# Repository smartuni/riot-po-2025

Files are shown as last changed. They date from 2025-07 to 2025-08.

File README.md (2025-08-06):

# RIOT im Internet of Things, Sommersemester 2025

Welcome to the primary repository of the RIOT im Internet of Things project for the Summer 2025 semester at HAW Hamburg. The project was concerned with designing, implementing and presenting technologies to improve the city of Hamburg's methods of managing its harbor's floodgates.

## The Current Situation

Currently, the methods for ensuring floodgates are closed in the event of a flood are inefficient. Field workers receive orders, send updates and otherwise communicate with the central office via walkie-talkies. The central office relies on pen-and-paper record-keeping to log events, such as gates being opened or closed.

## Our Proposed Solution

The solution proposed and developed by our team is as follows: 
<ul>
  <li>Floodgates will be fitted with sensors, called "GateMates," which autonomously report the state of the gate (open or closed) to a server located in the central office.</li>
  <li>Field workers will be issued devices, called "SenseMates," which receive orders from the central office. SenseMates will also record the state of nearby gates by communicating with the GateMates, enabling workers to confirm or refute the state reported by the GateMate.</li>
  <li>The workers at the office will be given a web app with a user interface, allowing them to track the status of gates in real time, as well as providing a digital record of the status of gates and allowing them to issue orders without the need for walkie-talkie communication.</li>
</ul>

Our proposed solution replaces the inefficient methods currently used by the city of Hamburg with fast and reliable digital methods, saving crucial time in the event of a flood.

## How to start the project

### SenseGate

- Connect to Power
- Wait until blue LED is on
- Red LED indicates if door is open (LED off) or closed (LED on)
- Blue LED indicates, if a state update is in progress (LED off). 
- There is a time runoff, which is triggered/restarted on any sensor input. When blue LED is on, the update is processed and sent via LoraWAN.    

#### Deployment

Before flashing make sure [signature keys](nodes/firmware/custom-modules/key-distro/README.md) are generated! 

#### Testing 

```make all flash RIOT_CONFIG_USE_TEST=1```

#### Production

```make all flash RIOT_CONFIG_DEVICE_ID=<GATE_ID>```

### SenseMate

#### Startup
- Use power switch
- Wait until screen is ready

#### Deployment

Before flashing make sure [signature keys](nodes/firmware/custom-modules/key-distro/README.md) are generated! 

#### Testing 

```make all flash RIOT_CONFIG_USE_TEST=1```

#### Production

```make all flash RIOT_CONFIG_DEVICE_ID=<GATE_ID>```

### How to start frontend and backend

#### Requirements to Start the Frontend
- nodejs installed
- npm installed

#### Frontend StartUp
[frontend StartUp](server/frontend/README.md)

#### Backend StartUp
[backend StartUp](server/backend/README.md)

## Nodes

### Overview <div id='overview'/>

SenseMate <div id='overview-sensemate'/>

- node carried around by workers
- receive from and propagate data to other nodes via BLE-module
- receive from and send data to server via LoRa-module

SenseGate <div id='overview-sensegate'/>

- node attached to flood gates
- receive from and propagate data to other nodes via BLE-module
- receive from and send data to server via LoRa-module

Server <div id='overview-server'/>

- receive from and send data to nodes via LoRa-Module
- display real-time accumulated data

## Used Hardware <div id='used-hardware'/>

- Board: Nordic nRF52840
- Power Switch
- Battery
- Thumbwheel
- Navigation
- Display
- Soundbuzzer
- Vibrationmotor

**SenseMate** is a battery-powered IoT device for monitoring and controlling floodgates. It communicates over BLE and LoRaWAN and provides tactile, visual, and acoustic feedback.

## Key Features <div id='key-features'/>

- **MCU**: [Adafruit Feather nRF52840 Sense](https://www.digikey.de/de/products/detail/adafruit-industries-llc/4516/11684829) (nRF52840 with BLE)
- **LoRa Module**: [Adafruit RFM95W](https://www.digikey.de/de/products/detail/adafruit-industries-llc/3231/6193593)
- **LoRa Antenna**: [Molex 2111400100](https://www.digikey.de/de/products/detail/molex/2111400100/9953925)
- **OLED Display**: [AZDelivery 0.96" SSD1306 I2C](https://www.amazon.de/AZDelivery-Display-Arduino-Raspberry-gratis/dp/B074NJMPYJ?th=1)
- **Thumbwheel Switch**: [SparkFun COM-08184](https://www.digikey.de/de/products/detail/sparkfun-electronics/08184/8543391)
- **Buzzer**: [TDK PS1240P02BT](https://www.digikey.de/de/products/detail/tdk-corporation/PS1240P02BT/935924) (connected to A2)
- **Vibration Motor**: [Seeed 316040004](https://www.digikey.de/de/products/detail/seeed-technology-co-ltd/316040004/5487673) (via NPN + GPIO D3)
- **Power Switch**: [C&K OS102011MA1QN1](https://www.digikey.de/de/products/detail/c-k/OS102011MA1QN1/1981430)
- **Battery**: [Amazon LiPo 1S 450mAh](https://www.amazon.de/dp/B0C5LD55HN) 

## Pinout Summary <div id='pin-summary'/>

| Peripheral         | Connection Type   | MCU Pin       |
|--------------------|-------------------|----------------|
| LoRa SPI           | SPI               | SCK / MOSI / MISO |
| LoRa CS            | GPIO              | D10            |
| LoRa RST           | GPIO              | D9             |
| LoRa IRQ (DIO0)    | GPIO              | D6             |
| LoRa DIO1 / DIO2   | GPIO              | D5 / D4        |
| OLED Display       | I²C               | SDA / SCL      |
| Thumbwheel         | Digital Inputs    | A0 / A1 / A3   |
| Buzzer             | PWM/GPIO          | A2             |
| Vibration Motor    | GPIO (via NPN)    | D3             |
| Battery Voltage    | Analog Input      | A6             |

---

This document is intended for firmware developers. All components are prewired—just refer to the pinout and RIOT board support to begin implementing logic.

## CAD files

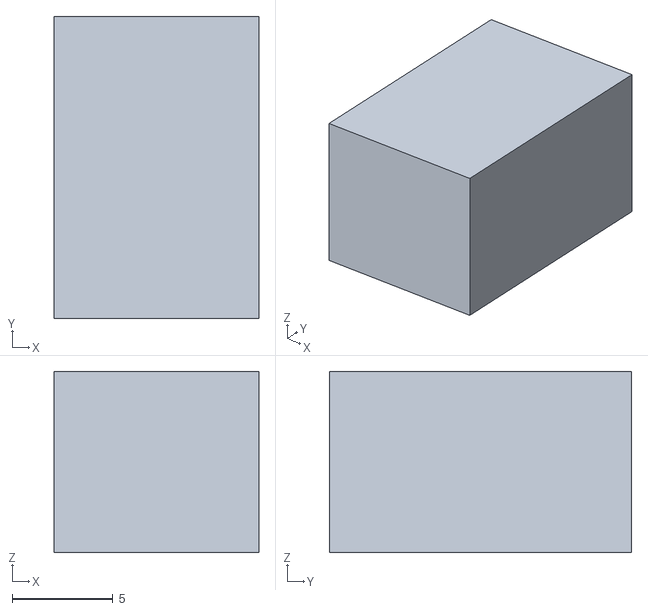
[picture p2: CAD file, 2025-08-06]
nodes/hardware/SenseMate/SenseMate3D/Case_v2.2_PCBBracket.stl
10.2 x 15.0 x 9.00

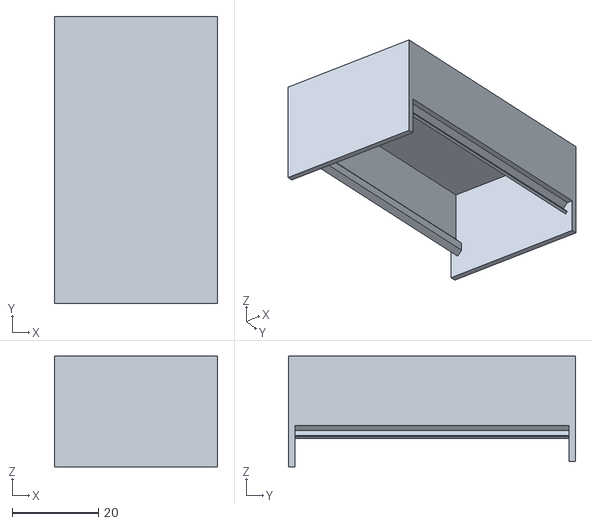
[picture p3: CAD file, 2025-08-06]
nodes/hardware/SenseMate/SenseMate3D/Case_v2.2_Back.stl
37.7 x 66.5 x 25.6

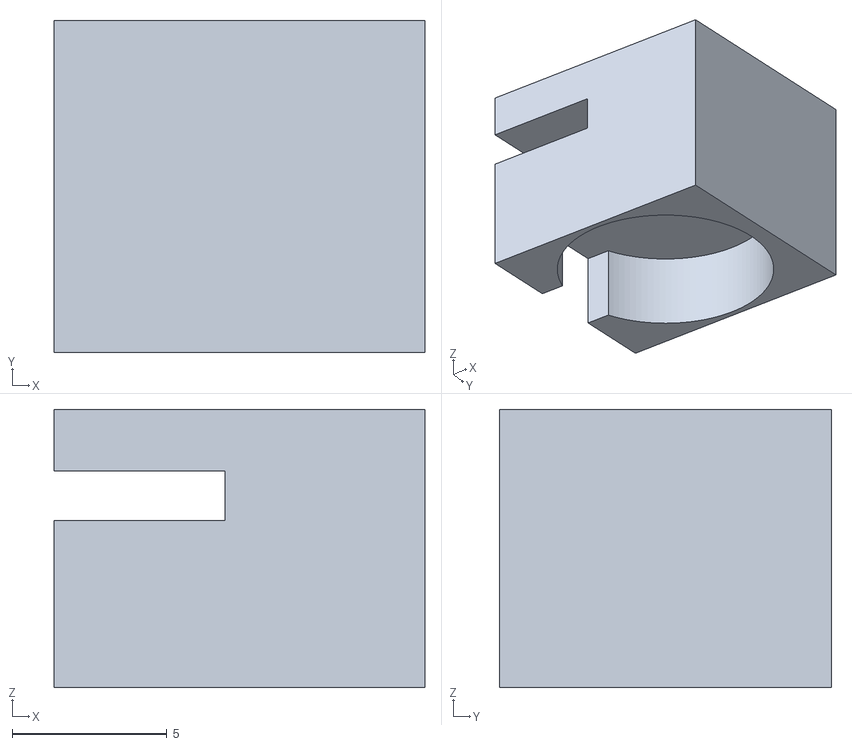
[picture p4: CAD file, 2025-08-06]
nodes/hardware/SenseMate/SenseMate3D/Case_v2.2_VibraMotorBracket.stl
12.0 x 10.8 x 9.00

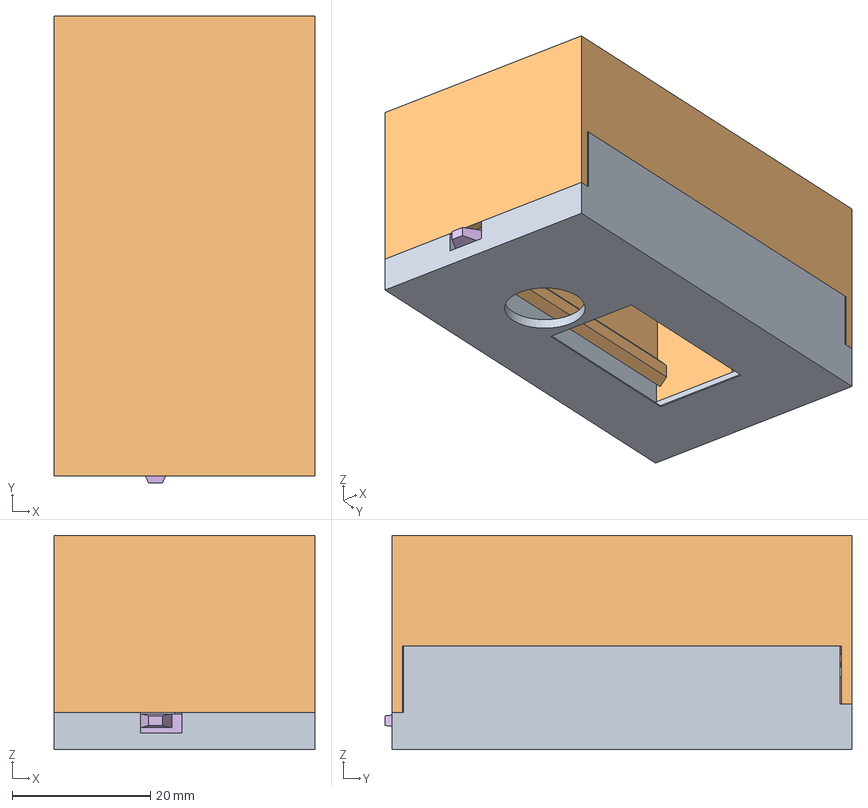
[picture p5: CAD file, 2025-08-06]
nodes/hardware/SenseMate/SenseMate3D/riot-po-2025-sensemate_newpcb.FCStd
37.7 x 67.5 x 31.0 mm
FrontFusion
BackFusion
DisplayHolderBracket
PCBCornerBracket
VibrationMotorBracket
PowerSwitchBracket

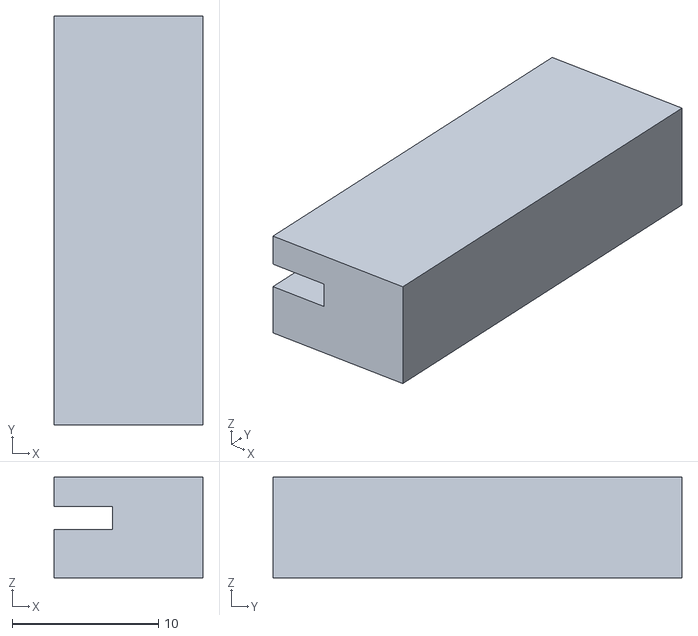
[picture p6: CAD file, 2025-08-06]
nodes/hardware/SenseMate/SenseMate3D/Case_v2.2_DisplayBracket.stl
10.2 x 28.0 x 6.90

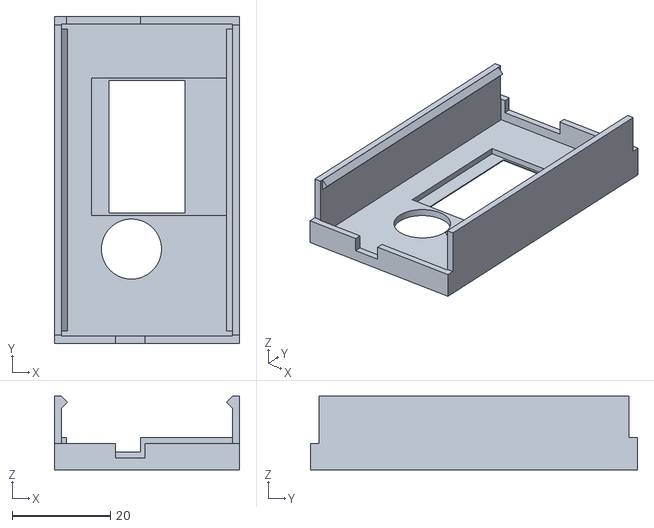
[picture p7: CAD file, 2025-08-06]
nodes/hardware/SenseMate/SenseMate3D/Case_v2.2_Front.stl
37.7 x 66.5 x 15.0

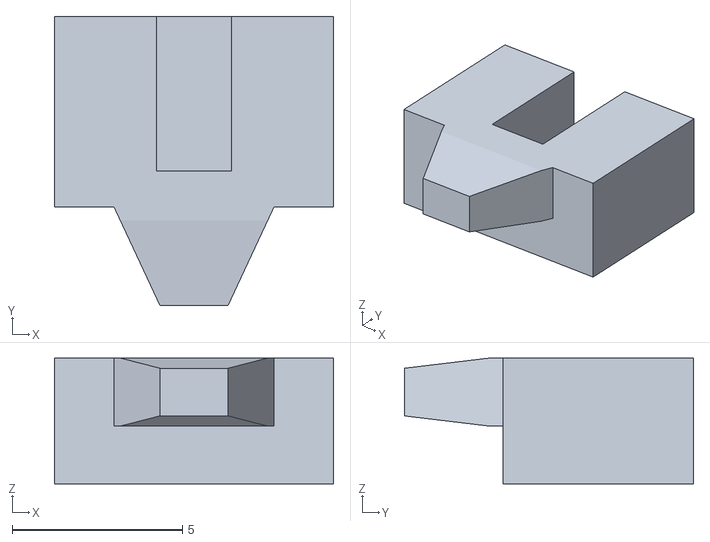
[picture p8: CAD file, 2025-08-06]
nodes/hardware/SenseMate/SenseMate3D/Case_v2.2_PowerSwitchExtensionBracket.stl
8.20 x 8.50 x 3.70

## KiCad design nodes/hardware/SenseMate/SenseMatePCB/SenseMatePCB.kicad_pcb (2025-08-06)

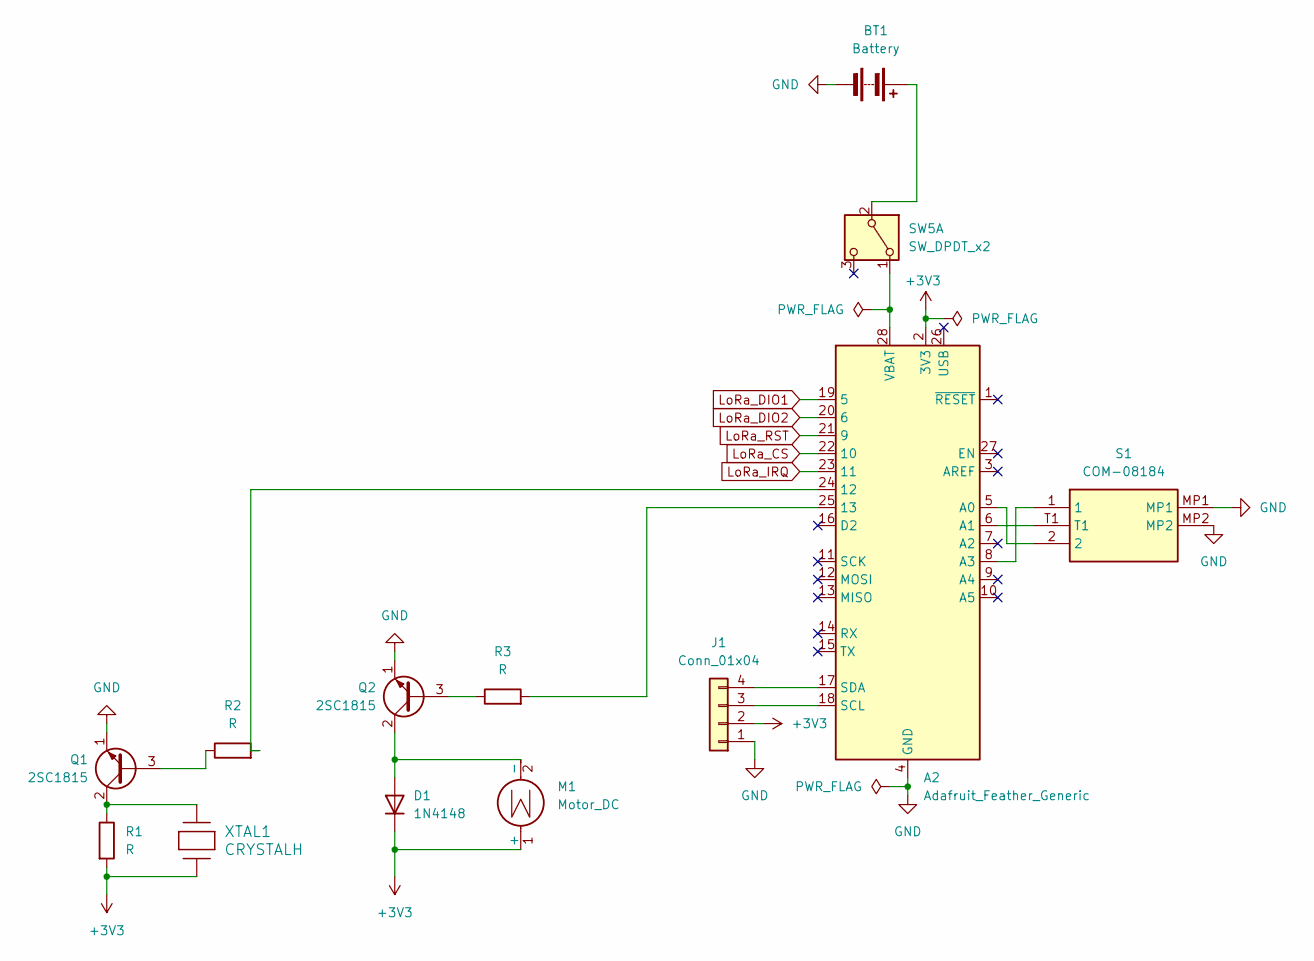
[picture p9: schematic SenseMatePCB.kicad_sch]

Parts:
A2: Adafruit_Feather_Generic; Adafruit_Feather_Sense
BT1: Battery; JST_PH_S2B-PH-K_1x02_P2.00mm_Horizontal
D1: 1N4148; D_SOD-323
J1: Conn_01x04; PinHeader_1x04_P2.54mm_Vertical
M1: Motor_DC; PinHeader_1x02_P2.54mm_Vertical
Q1, Q2: 2SC1815; SOT-23
R1, R2, R3: R; R_0805_2012Metric
S1: COM-08184; COM08184; Manufacturer_Part_Number COM-08184
SW5: SW_DPDT_x2; OS102011MA1QN1
XTAL1: CRYSTALH; XTAL_PS1240P02BT_TDK

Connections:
+3V3: A2.2 (3V3), D1.1 (K), J1.2, M1.1 (+), R1.2, XTAL1.1
GND: A2.4 (GND), BT1.2 (-), J1.1, Q1.1 (E), Q2.1 (E), S1.MP1, S1.MP2
LoRa_CS: A2.22 (10)
LoRa_DIO1: A2.19 (5)
LoRa_DIO2: A2.20 (6)
LoRa_IRQ: A2.23 (11)
LoRa_RST: A2.21 (9)
unnamed: A2.24 (12), R2.2
unnamed: A2.25 (13), R3.2
unnamed: A2.5 (A0), S1.2
unnamed: A2.6 (A1), S1.T1
unnamed: A2.8 (A3), S1.1
unnamed: A2.18 (SCL), J1.3
unnamed: A2.17 (SDA), J1.4
unnamed: A2.28 (VBAT), SW5.1 (A)
unnamed: BT1.1 (+), SW5.2 (B)
unnamed: D1.2 (A), M1.2 (-), Q2.2 (C)
unnamed: Q1.3 (B), R2.1
unnamed: Q1.2 (C), R1.1, XTAL1.2
unnamed: Q2.3 (B), R3.1

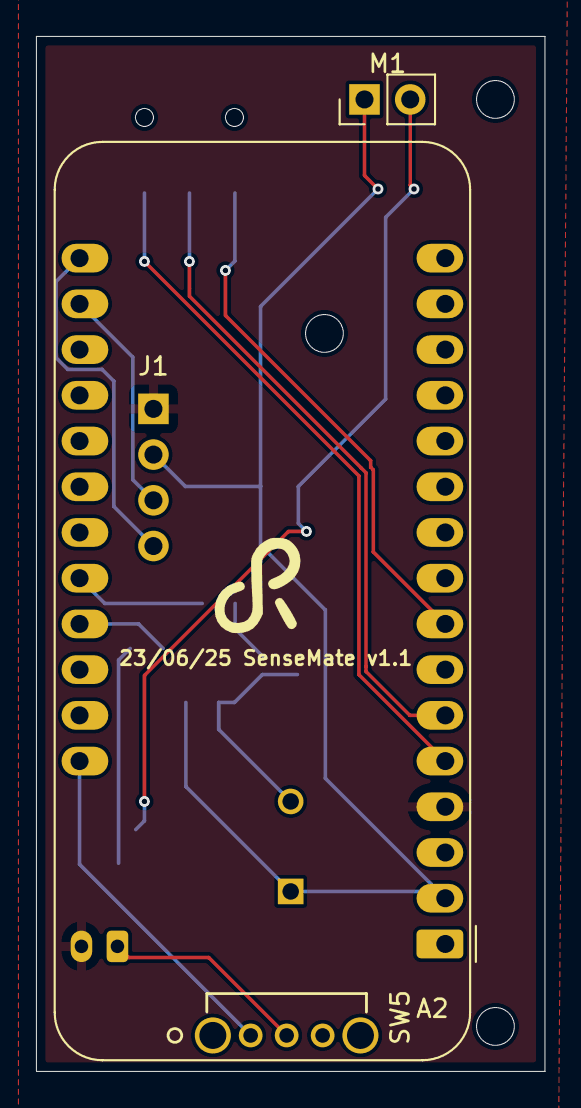
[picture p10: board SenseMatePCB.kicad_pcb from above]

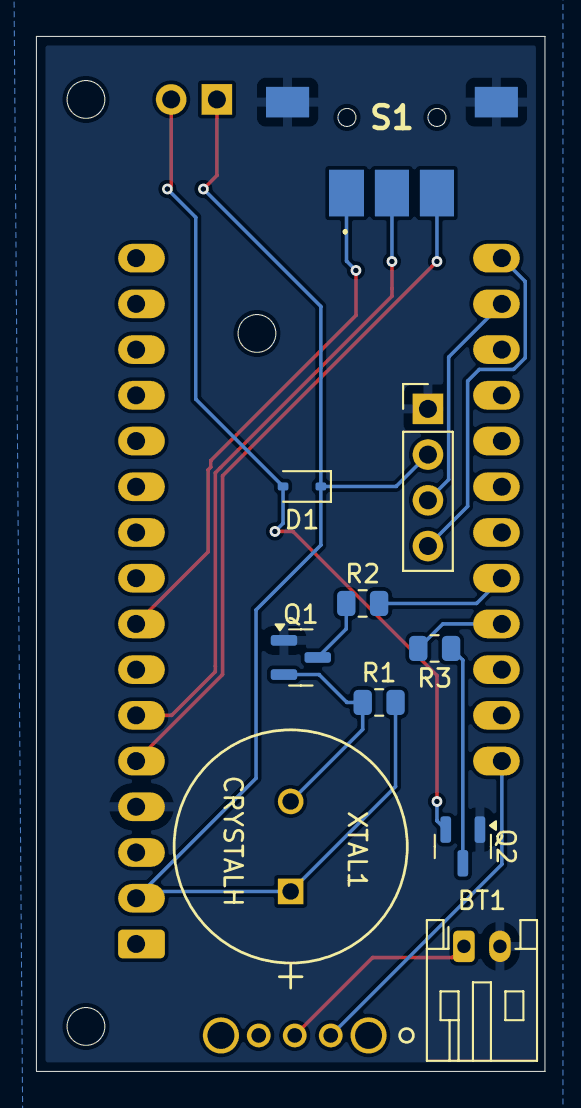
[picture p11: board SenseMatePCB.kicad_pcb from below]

Board: 2 copper layers, 28.2 x 57.5 mm, 13 parts (10 on the bottom side), 15 nets.

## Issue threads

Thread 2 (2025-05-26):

Finalize schematic capture and review

avvocato-sudo, 2025-05-26:
Ensure the full schematic is complete, all components are added, values are correct, and the circuit design is logically sound. Perform a peer or team review before moving to the layout phase.

Closed 2025-06-02.

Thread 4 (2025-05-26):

Complete board layout and routing

avvocato-sudo, 2025-05-26:
Place all components on the PCB layout, define the board outline, and route all connections while following design rules (trace width, spacing, etc.).

Closed 2025-06-08.

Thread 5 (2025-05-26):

[#004]  Run and resolve DRC issues

avvocato-sudo, 2025-05-26:
Perform a full Design Rules Check (DRC) to identify and fix any layout violations such as clearance errors, overlapping traces, or unconnected pads.

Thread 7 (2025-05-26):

Generate and validate Gerber + drill files

avvocato-sudo, 2025-05-26:
Export Gerber and drill files required for PCB manufacturing. Validate the output in a Gerber viewer to ensure everything renders correctly.

Closed 2025-06-10.

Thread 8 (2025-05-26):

[#007] Prepare manufacturing documentation (BOM, fab notes, etc.)

avvocato-sudo, 2025-05-26:
Generate and clean up the Bill of Materials (BOM), add fabrication notes if needed, and double-check part availability and footprints.

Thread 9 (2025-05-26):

Create release package for manufacturer

avvocato-sudo, 2025-05-26:
Bundle the final files (.sch, .kicad_pcb, Gerbers, drill, BOM, readme) into a release ZIP or directory. Optionally tag the repo for release.

Closed 2025-07-11.

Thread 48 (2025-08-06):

downlinks do not make it to the device in a test

makrej, 2025-08-06:
downlinks are send but not received by the device. the cause of this misbehaviour is not detectable. Futher test cannot be executed. In earlier tests the device crashed.

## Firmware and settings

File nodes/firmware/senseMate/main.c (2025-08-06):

#include "include/displayDemo.h"
#include "ztimer.h"
#include <stdio.h>
#include <list.h>
#include "board.h"
#include "periph/gpio.h"
#include "ztimer.h"
#include "include/interrupts.h"
#include "include/events_creation.h"
#include "tables.h"
#include "mate_lorawan.h"
#include "include/new_menu.h"
#include "include/soundModule.h"
#include "include/vibrationModule.h"

#include "mate_ble.h"

//void fill_tables_test(void); //for menu testing purposes

char ble_send_stack[2*THREAD_STACKSIZE_DEFAULT];
char ble_reicv_stack[2*THREAD_STACKSIZE_DEFAULT];

int lorawan_started = -1;

int main(void) {
    //ztimer_sleep(ZTIMER_MSEC, 3000); //if use term activate sleep to see all prints
    init_interrupt();
    init_sound_module();
    init_vibration_module();
    event_post(&sound_queue, &start_sound_event);
    //startup_sound();

    //printf("Display demo started.\n");
    init_display();
    printf("Device Type: %d device id: %d\n",DEVICE_TYPE, DEVICE_ID);
    printf("Display initialized.\n");
    //init_menu();
    init_new_menu();
    //set_current_meustate(INIT);
    update_menu_display();
    init_event();
    init_tables();
    //is_state_entry receiveide_is_state;
    //int hallo = get_is_state_entry(1, &receiveide_is_state);
    //printf("Gate Id %d\n", receiveide_is_state.gateID);
    //fill_tables_test();
    
    update_menu_from_tables();
    //(void) test_merge;
    //(void) hallo;
    // const is_state_entry* table = get_is_state_table();
    // for (int i = 0; i < 255; i++){
    //     printf("ID: %d, State: %d, Time: %d\n", table[i].gateID, table[i].state, table[i].gateTime);
    // }

    

    puts("starting ble");
    if (BLE_SUCCESS == ble_init()){
        puts("Ble init complete");
    } else {
        puts("BLE not started");
    }

    thread_create(
        ble_send_stack,
        sizeof(ble_send_stack),
        THREAD_PRIORITY_MAIN - 1,
        THREAD_CREATE_STACKTEST,
        ble_send_loop,
        NULL,
       "bleSend"
    );

    ble_receive_thread_args_t args = {
        .receive_queue = &events_creation_queue,
        .receive_event = &eventBleNews,

    };

    thread_create(
        ble_reicv_stack,
        sizeof(ble_reicv_stack),
        THREAD_PRIORITY_MAIN - 1,
        THREAD_CREATE_STACKTEST,
        ble_receive_loop,
        &args,
       "bleRecv"
    );

    lorawan_started = start_lorawan();

    puts("entering main loop");
    while (1)
    {
        if(lorawan_started == -1){
            lorawan_started = start_lorawan();
        }
        ztimer_sleep(ZTIMER_MSEC, 1000);
        //refresh_display();
        increment_device_timestamp();
    }
    
    printf("Display demo finished.\n");

    return 0;
}

void fill_tables_test(void){
    is_state_entry test;
    test.gateID = 1;
    test.state = 1;
    test.gateTime = 20000;
    int test_merge = set_is_state_entry(&test);
    test.gateID = 2;
    test.state = 1;
    test.gateTime = 20000;
    test_merge = set_is_state_entry(&test);
    test.gateID = 3;
    test.state = 1;
    test.gateTime = 20000;
    test_merge = set_is_state_entry(&test);
    test.gateID = 4;
    test.state = 1;
    test.gateTime = 20000;
    test_merge = set_is_state_entry(&test);
    test.gateID = 5;
    test.state = 1;
    test.gateTime = 20000;
    test_merge = set_is_state_entry(&test);
    test.gateID = 6;
    test.state = 1;
    test.gateTime = 20000;
    test_merge = set_is_state_entry(&test);
    test.gateID = 7;
    test.state = 1;
    test.gateTime = 20000;
    test_merge = set_is_state_entry(&test);
    printf("Test merge: %d\n", test_merge);

    seen_status_entry test_seen;
    test_seen.gateID = 1;
    test_seen.status = 1;
    test_seen.gateTime = 2000;
    test_seen.senseMateID = 3;
    int test_seen_merge = set_seen_status_entry(&test_seen);
    test_seen.gateID = 2;
    test_seen.status = 0;
    test_seen.gateTime = 25000;
    test_seen.senseMateID = 5;
    test_seen_merge = set_seen_status_entry(&test_seen);
    test_seen.gateID = 3;
    test_seen.status = 1;
    test_seen.gateTime = 30000;
    test_seen.senseMateID = 7;
    test_seen_merge = set_seen_status_entry(&test_seen);
    test_seen.gateID = 4;
    test_seen.status = 0;
    test_seen.gateTime = 28647;
    test_seen.senseMateID = 5;
    test_seen_merge = set_seen_status_entry(&test_seen);
    test_seen.gateID = 5;
    test_seen.status = 0;
    test_seen.gateTime = 1000;
    test_seen.senseMateID = 3;
    test_seen_merge = set_seen_status_entry(&test_seen);
    test_seen.gateID = 6;
    test_seen.status = 1;
    test_seen.gateTime = 5000;
    test_seen.senseMateID = 7;
    test_seen_merge = set_seen_status_entry(&test_seen);
    test_seen.gateID = 7;
    test_seen.status = 1;
    test_seen.gateTime = 10000;
    test_seen.senseMateID = 5;
    test_seen_merge = set_seen_status_entry(&test_seen);
    printf("Test merge: %d\n", test_seen_merge);
    
    target_state_entry test_target;
    test_target.gateID = 1;
    test_target.state = 1;
    test_target.timestamp = 20000;
    int test_target_merge = set_target_state_entry(&test_target);
    test_target.gateID = 2;
    test_target.state = 0;
    test_target.timestamp = 25000;
    test_target_merge = set_target_state_entry(&test_target);
    test_target.gateID = 3;
    test_target.state = 1;
    test_target.timestamp = 30000;
    test_target_merge = set_target_state_entry(&test_target);
    test_target.gateID = 4;
    test_target.state = 0;
    test_target.timestamp = 28647;
    test_target_merge = set_target_state_entry(&test_target);
    test_target.gateID = 5;
    test_target.state = 0;
    test_target.timestamp = 1000;
    test_target_merge = set_target_state_entry(&test_target);
    test_target.gateID = 6;
    test_target.state = 1;
    test_target.timestamp = 5000;
    test_target_merge = set_target_state_entry(&test_target);
    test_target.gateID = 7;
    test_target.state = 1;
    test_target.timestamp = 10000;
    test_target_merge = set_target_state_entry(&test_target);
    printf("Test merge: %d\n", test_target_merge);

    jobs_entry test_job;
    test_job.gateID = 1;
    test_job.done = 1;
    test_job.priority = 1;
    int test_job_merge = set_jobs_entry(&test_job);
    test_job.gateID = 2;
    test_job.done = 0;
    test_job.priority = 2;
    test_job_merge = set_jobs_entry(&test_job);
    test_job.gateID = 3;
    test_job.done = 0;
    test_job.priority = 3;
    test_job_merge = set_jobs_entry(&test_job);
    test_job.gateID = 4;
    test_job.done = 0;
    test_job.priority = 2;
    test_job_merge = set_jobs_entry(&test_job);
    test_job.gateID = 5;
    test_job.done = 0;
    test_job.priority = 0;
    test_job_merge = set_jobs_entry(&test_job);
    test_job.gateID = 6;
    test_job.done = 0;
    test_job.priority = 3;
    test_job_merge = set_jobs_entry(&test_job);
    test_job.gateID = 7;
    test_job.done = 0;
    test_job.priority = 2;
    test_job_merge = set_jobs_entry(&test_job);
    printf("Test merge: %d\n", test_job_merge);

    timestamp_entry test_timestamp;
    test_timestamp.gateID = 1;
    test_timestamp.timestamp = 55000;
    test_timestamp.rssi = -50;
    int test_timestamp_merge = set_timestamp_entry(&test_timestamp);
    test_timestamp.gateID = 2;
    test_timestamp.timestamp = 60000;
    test_timestamp.rssi = -100;
    test_timestamp_merge = set_timestamp_entry(&test_timestamp);
    test_timestamp.gateID = 3;
    test_timestamp.timestamp = 66000;
    test_timestamp.rssi = 0;
    test_timestamp_merge = set_timestamp_entry(&test_timestamp);
    test_timestamp.gateID = 4;
    test_timestamp.timestamp = 70000;
    test_timestamp.rssi = 170;
    test_timestamp_merge = set_timestamp_entry(&test_timestamp);
    test_timestamp.gateID = 5;
    test_timestamp.timestamp = 8000;
    test_timestamp.rssi = -20;
    test_timestamp_merge = set_timestamp_entry(&test_timestamp);
    test_timestamp.gateID = 6;
    test_timestamp.timestamp = 9000;
    test_timestamp.rssi = -30;
    test_timestamp_merge = set_timestamp_entry(&test_timestamp);
    test_timestamp.gateID = 7;
    test_timestamp.timestamp = 10000;
    test_timestamp.rssi = 0;
    test_timestamp_merge = set_timestamp_entry(&test_timestamp);
    printf("Test merge: %d\n", test_timestamp_merge);
}

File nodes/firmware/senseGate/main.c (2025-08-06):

#include <stdio.h>

#include "board.h"
#include "ztimer.h"
#include "thread.h"
#include "tables.h"
#include "mate_lorawan.h"
#include "mate_ble.h"

#include <stdio.h>

#include "include/detectDoorStatus.h"
#include "include/event_creation.h"

#define TIME_PERIOD_TABLE_UPDATE 30 // const defines time to update table periodically


char ble_send_stack[2*THREAD_STACKSIZE_DEFAULT];
char ble_reicv_stack[2*THREAD_STACKSIZE_DEFAULT];

int main(void){

    puts("starting");
    init__door_interrupt();
    puts("init tables");
    init_tables();
    
    puts("reading initial door state");
    uint8_t inital_door_state = initial_door_state();
    // write initial_door_state to table
    update_status(inital_door_state);

    // write to table
    puts("write to table");
    is_state_entry table_entry;
    table_entry.gateID = GATE_ID;
    table_entry.state = inital_door_state;
    table_entry.gateTime = get_device_timestamp();

    // if (TABLE_SUCCESS == set_is_state_entry()){
     if (TABLE_UPDATED == set_is_state_entry(&table_entry)){
        
        if (!inital_door_state) {
            
            puts("door closed initially");
        }
        else {
            
            puts("door opened initially");
        }
    } else {
        puts("could not write to table");
    }

    // start lorawan
    puts("starting lorawan");
    int lorawanstarted = start_lorawan();
    if (-1 == lorawanstarted){
        printf("starting lorawan failed");
    }


        //start thread init bluetooth
    puts("starting ble");
    if (BLE_SUCCESS == ble_init()){
        puts("Ble init complete");
    } else {
        puts("BLE not started");
    }


    thread_create(
        ble_send_stack,
        sizeof(ble_send_stack),
        THREAD_PRIORITY_MAIN - 2,
        THREAD_CREATE_STACKTEST,
        ble_send_loop,
        NULL,
       "bleSend"
    );
    
     thread_create(
         ble_reicv_stack,
         sizeof(ble_reicv_stack),
         THREAD_PRIORITY_MAIN - 3,
         THREAD_CREATE_STACKTEST,
         ble_receive_loop,
         NULL,
        "bleRecv"
     );

    int timeToUpdateTable = 0; // var to update table periodically
    
    while(1){

        
        if (-1 == lorawanstarted){
            lorawanstarted = start_lorawan();
        }
        
        increment_device_timestamp();
        ztimer_sleep(ZTIMER_MSEC,1000);
    
        if (timeToUpdateTable == TIME_PERIOD_TABLE_UPDATE) {
            is_state_entry table_update_entry;
            table_update_entry.gateID = GATE_ID;
            table_update_entry.state = get_status();
            table_update_entry.gateTime = get_device_timestamp();

            if (TABLE_UPDATED == set_is_state_entry(&table_update_entry)){
                puts("Table updated with newest timestamp");
            }
            timeToUpdateTable = 0;
        } else {
            timeToUpdateTable++;
        }

        

    }
    return 0;
}

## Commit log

2025-05-19 inital kicad design
    [SenseMatePCB.kicad_pcb, SenseMatePCB.kicad_sch]
2025-05-23 Added sound buzzer to schmatic
    [SenseMatePCB.kicad_sch]
2025-05-25 schematic nearly finished, only lcd needs to be added
    [SenseMatePCB.kicad_sch]
2025-05-25 added own version of butto
    [SenseMatePCB.kicad_sch]
2025-05-26 changed the button to own implementation
    [SenseMatePCB.kicad_sch]
2025-05-26 Reorganized initial folder structure
    [SenseMatePCB.kicad_pcb, SenseMatePCB.kicad_sch]
2025-05-26 Add working sample interrupt module
2025-06-02 Add debounce functionality; not working; try events next
    [detectDoorStatus.c, main.c]
2025-06-10 Add Debouncing; sending to lorawan missing
    [detectDoorStatus.c, event_creation.c, main.c]
2025-06-10 Node Branch update to main (#19)
    * Aufgabenverteilung
    * Notizen für Exercises
    * latest documentation
    * adjusted task for next week
    * readme moved
    * readme format fix
    * Tabellen
    * ble module created
    * add cose-service and example app
    * upgrade riot version
    * change to monocypher
    * fix stack_size when using monocypher
    * edit RIOT submodule to use own fork
    * Update README.md
    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
    [cose-service.h, main.c]
2025-06-14 Add Lorawan features: starting up thread and posting update event
2025-06-15 lorawan module finished for prototype show case
2025-06-15 change board name
2025-06-15 fixes git merge errors
    [tables.c]
2025-06-15 started with 3d design for sensemate
    [Unnamed.FCStd]
2025-06-15 started with 3d design for sensemate #26
    [Unnamed.FCStd]
2025-06-16 lassmal neue tables holen
2025-06-16 fixes pt.3 - compile successfully
    [tables.c]
2025-06-16 3d print ready for first sample #26
    [Unnamed.FCStd]
2025-06-16 added champfer on the sites #26
    [Unnamed.FCStd]
2025-06-16 Fixes; lorawan not starting
    [event_creation.c, main.c]
2025-06-16 Removed uneccesary thread for lorawan
2025-06-16 stl and printable format created
    [FirstPrintableDraft.stl]
2025-06-16 tested sending via lorawan - not working yet!
    [main.c, tables.c]
2025-06-16 I2C FAAAST
2025-06-22 Timer Module deleted during merge
2025-06-23 second draft for sensemate casing #27
    [darft2.FCStd, riot-sensmate-case-darft2.stl]
2025-06-23 Fix table update issues
    [event_creation.c, main.c]
2025-06-23 Update LED indicators
2025-06-23 Fixed size of cbor msg, added counter for entries
    [main.c, tables.c]
2025-06-23 Fixed sizing of cbor msgs, added counter
    [main.c, tables.c]
2025-06-23 revision of pcb and 3d design #27 #28
    [SenseMatePCB-B_Cu.gbl, SenseMatePCB-B_Mask.gbs, SenseMatePCB-B_Paste.gbp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]
2025-06-23 changed motor connector to 2-pin-header
    [SenseMatePCB.kicad_pcb, SenseMatePCB.kicad_sch]
2025-06-23 new 3d draft for new pcb #27 #28
    [SenseMatePCB.kicad_pcb, darft3.FCStd, riot-po-2025-sensemate_newpcb-v0.1.stl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]
2025-06-24 nodes/hardware/sensemate/sensematepcb: ordered version 1.1
    [SenseMatePCB-B_Cu.gbl, SenseMatePCB-B_Mask.gbs, SenseMatePCB-B_Paste.gbp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]
2025-06-30 advertisement change and thread
2025-06-30 Fixed Security config to prevent non-logged in users making requests
    [SecurityConfig.java]
2025-06-30 Added guest view page that does not require logging in or creating an account and also added popups that prevent users from accessing the dashboard page when not logged in
    [SecurityConfig.java]
2025-06-30 is_state_table_to_cbor_many fixed and now working
    [tables.c]
2025-06-30 refined 3d print #26
    [riot-po-2025-sensemate_newpcb-draft2.stl, riot-po-2025-sensemate_newpcb-draft3.stl, riot-po-2025-sensemate_newpcb-draft4.stl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]
2025-06-30 Signing crashing on receive
    [main.c]
2025-07-01 Added the Priority to the GateEntity and the UI u can choose which gate should have what priority.
    Also changed the Layout of the table so we have Pending Jobs which you can change regardles off the current status and added a button for showing the activities
2025-07-02 finished top, revised bottom
    [riot-po-2025-sensemate_newpcb.FCStd, riot-po-2025-sensemate_newpcb_top.FCStd]
2025-07-03 nodes/hardware/SenseMate/SenseMate3D: update 3d design file of the SenseMate case
    *merge top and bottom part into the same file to allow referencing the same variables
    *add some tolerance definitions to compensate for imperfect 3d prints
    *improve snap fit
    *add power switch extension to compensate for too large battery/ too short PCB (shorter battery would allow smaller case)
    *add some brackets to hold the PCB and screen in place when inserted into the case
    [riot-po-2025-sensemate_newpcb.FCStd]
2025-07-03 nodes/hardware/SenseMate/SenseMate3D: drop old design file of box part
    [riot-po-2025-sensemate_newpcb_top.FCStd]
2025-07-03 nodes/hardware/SenseMate/SenseMate3D: drop old stl files and add new ones
    [FirstPrintableDraft.stl, riot-po-2025-sensemate_newpcb-Fusion_draft5.stl, riot-po-2025-sensemate_newpcb-draft2.stl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]
2025-07-04 nodes/hardware/SenseMate/SenseMate3D: improve tolerances, add vibra motor bracket, add new stl exports
    [riot-po-2025-sensemate_newpcb.FCStd, riot-po-2025-sensemate_newpcb_case_v2.1_back.stl, riot-po-2025-sensemate_newpcb_case_v2.1_display_bracket.stl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]
2025-07-06 Applied fix from is_state_table_to_cbor_many to remaining *_table_to_cbor_many functions
    [tables.c]
2025-07-07 vibrating action going on HOT
    [displayDemo.c, main.c, soundModule.c]
2025-07-07 sound threaded
2025-07-07 Fixed cbor_to_table_test to pass param to merge
    [tables.c]
2025-07-07 added device_timestamp counter in tables
2025-07-08 Change thread prio; add timestamp functionality for senseGate
2025-07-08 DEVICE_TYPE & DEVICE_ID in makefile
2025-07-09 in signing DEVICE_ID -> KEY_ID - DEVICE_ID now ID of sensemate/gatemate
2025-07-09 Device ID in make-call configurable
2025-07-09 gate_mate DECICE_ID configurable in make call and DEVICE_TYPE=0 present
2025-07-09 nodes/hardware/SenseMate/SenseMate3D: improve snap, increase case size a bit, improve bracket spacing
    [riot-po-2025-sensemate_newpcb.FCStd]
2025-07-09 Update publish downlinks for all devices - need to be tested with real devices
2025-07-09 Add: RequestCheck in confidence, fix some small bugs, Update Device Registry
2025-07-09 Device type and Device ID added
2025-07-09 Introduced DownlinkCounter as Entity the DownlinkCounter will reset everyday at 00:00 if ten downlinks have been sent the button wont work anymore. if you want to reset the counter restart the server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
2025-07-11 nodes/hardware/SenseMate/logic/soundModule: fix event queue init
    [soundModule.c]
2025-07-11 nodes/hardware/SenseMate/SenseMate3D: update 3D design file
    [riot-po-2025-sensemate_newpcb.FCStd]
2025-07-11 nodes/hardware/SenseMate/SenseMate3D: remove old design and backup files
    [Unnamed.FCStd, darft2.FCStd, darft3.FCStd]
2025-07-11 nodes/hardware/SenseMate/SenseMate3D: remove old stl files
    [riot-po-2025-sensemate_newpcb_case_v2.0_back.stl, riot-po-2025-sensemate_newpcb_case_v2.0_display_bracket.stl, riot-po-2025-sensemate_newpcb_case_v2.0_front.st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]
2025-07-11 nodes/hardware/SenseMate/SenseMate3D: remove old gcode and 3mf files
    [riot-po-2025-sensemate_newpcb-draft5.3mf, riot-po-2025-sensemate_newpcb-v0.1.3mf, riot-sensmate-case-darft2.3mf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]
2025-07-11 nodes/hardware/SenseMate/SenseMate3D: add stl exports of current case design
    [Case_v2.2_Back.stl, Case_v2.2_DisplayBracket.stl, Case_v2.2_Front.stl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]
2025-07-11 implement correct device ID and type handling
2025-07-11 removed wrong function call
    [main.c]
2025-07-11 Replaced unnecessary switch case
2025-07-11 fix is_state_table_to_cbor_many_to_server arr size
    [event_creation.c, tables.c]
2025-07-11 why are we still in uni now, safe of computer crash
    [interrupts.c, main.c, soundModule.c]
2025-07-13 fix bricking device on disappearing close by devices
    [main.c]
2025-07-13 The Requested Status and pendingJob is not set to Requested_None and Pending_none ad the creation of a gate. so the filter didnt recognized it. fixed if any issues with that go to GateService.java ad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
2025-08-06 cut back on warnings by removing unnecessary imports, removed sections of commented-out code
2025-08-06 fix compile error because of wrong path
    [registerInterrupt.c]

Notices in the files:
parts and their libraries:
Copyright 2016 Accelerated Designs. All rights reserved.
